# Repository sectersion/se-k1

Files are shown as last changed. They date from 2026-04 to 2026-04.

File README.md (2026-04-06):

# Secure Element K1

This project is a small hardware password vault and crypto cold wallet using an ESP32-S3, a TPM (SLB9670), and a W25Q-series SPI flash chip.  

I created this project because a family member was talking about crypto wallets, and it gave me the idea of password managers. Online password managers are tied to one login and if that gets breached, all your accounts are gone. This implements a secure way to hold passwords, fully offline, not relying on cloud providers like Google.

## Features

- ESP32-S3 with USB HID keyboard output  
- TPM-backed master key for decrypting stored passwords  
- External SPI flash for record storage (ID, encrypted password, hashed PIN, MAC)  
- Button-based keypad input  
- PIN verification using SHA-256 with device-unique salt  
- Short-lived in-memory plaintext handling

## System

1. User enters a 4-digit record ID.  
2. Device loads the corresponding record from flash.  
3. User enters a 6-digit PIN.  
4. PIN is hashed and compared to the stored hash.  
5. If valid, the TPM unseals the master key.  
6. The encrypted password is decrypted using the TPM-provided key.  
7. The password is typed over USB HID.  
8. Plaintext is cleared.

## Components

| Designator | Footprint | Quantity | Value | LCSC Part # |
|---|---|---|---|---|
| 3V3 | TestPoint_Pad_D1.0mm | 1 | 3V3 | |
| 5V | TestPoint_Pad_D1.0mm | 1 | 5V | |
| BT1 | BatteryHolder_Renata_SMTU2032-LF_1x2032 | 1 | SMTU2032-LF | C18212226 |
| C1, C3, C7 | 0402 | 3 | 10uF | C315248 |
| C2 | CP_Elec_6.3x5.8 | 1 | 10uF | C128459 |
| C4 | 0402 | 1 | 0.1uF | C60474 |
| C5, C6 | 0402 | 2 | 100nF | C60474 |
| C8 | 0805 | 1 | 100nF | C49678 |
| D1 | D_SMA | 1 | SS14 | C2837270 |
| J1 | USB_C_Receptacle_HRO_TYPE-C-31-M-12 | 1 | USB_C_Receptacle_USB2.0_14P | C2765186 |
| R1, R2 | 0402 | 2 | 5.1k | C105872 |
| R3, R4, R5, R6, R8 | 0402 | 5 | 10k | C60490 |
| RST | SW_TS-1088-AR02016 | 1 | TS-1088-AR02016 | C720477 |
| RXD | TestPoint_Pad_D1.0mm | 1 | RX | |
| S1 | SW_TS-1088-AR02016 | 1 | 1 | C720477 |
| S2 | SW_TS-1088-AR02016 | 1 | 4 | C720477 |
| S3 | SW_TS-1088-AR02016 | 1 | 7 | C720477 |
| S4 | SW_TS-1088-AR02016 | 1 | 2 | C720477 |
| S5 | SW_TS-1088-AR02016 | 1 | 5 | C720477 |
| S6 | SW_TS-1088-AR02016 | 1 | 8 | C720477 |
| S7 | SW_TS-1088-AR02016 | 1 | 3 | C720477 |
| S8 | SW_TS-1088-AR02016 | 1 | 6 | C720477 |
| S9 | SW_TS-1088-AR02016 | 1 | 9 | C720477 |
| S10 | SW_TS-1088-AR02016 | 1 | 0 | C720477 |
| TXD | TestPoint_Pad_D1.0mm | 1 | TX | |
| U1 | ESP32-S2-MINI-1U | 1 | ESP32-S3-MINI-1U | C2980299 |
| U2 | QFN50P500X500X90-33N | 1 | SLM9670AQ20FW1311XTMA1 | C2651754 |
| U3 | SOIC127P790X216-8N | 1 | W25Q16JVSSIQ | C82317 |
| U4 | SOT-223-3_TabPin2 | 1 | AMS1117-3.3 | C6186 |

## Record Format

Each stored record contains:

- id: 4 bytes  
- encrypted_password: fixed length  
- encrypted_pin: 16-byte truncated SHA-256 hash  
- mac: record integrity field

## Pictures
3D model:


PCB:


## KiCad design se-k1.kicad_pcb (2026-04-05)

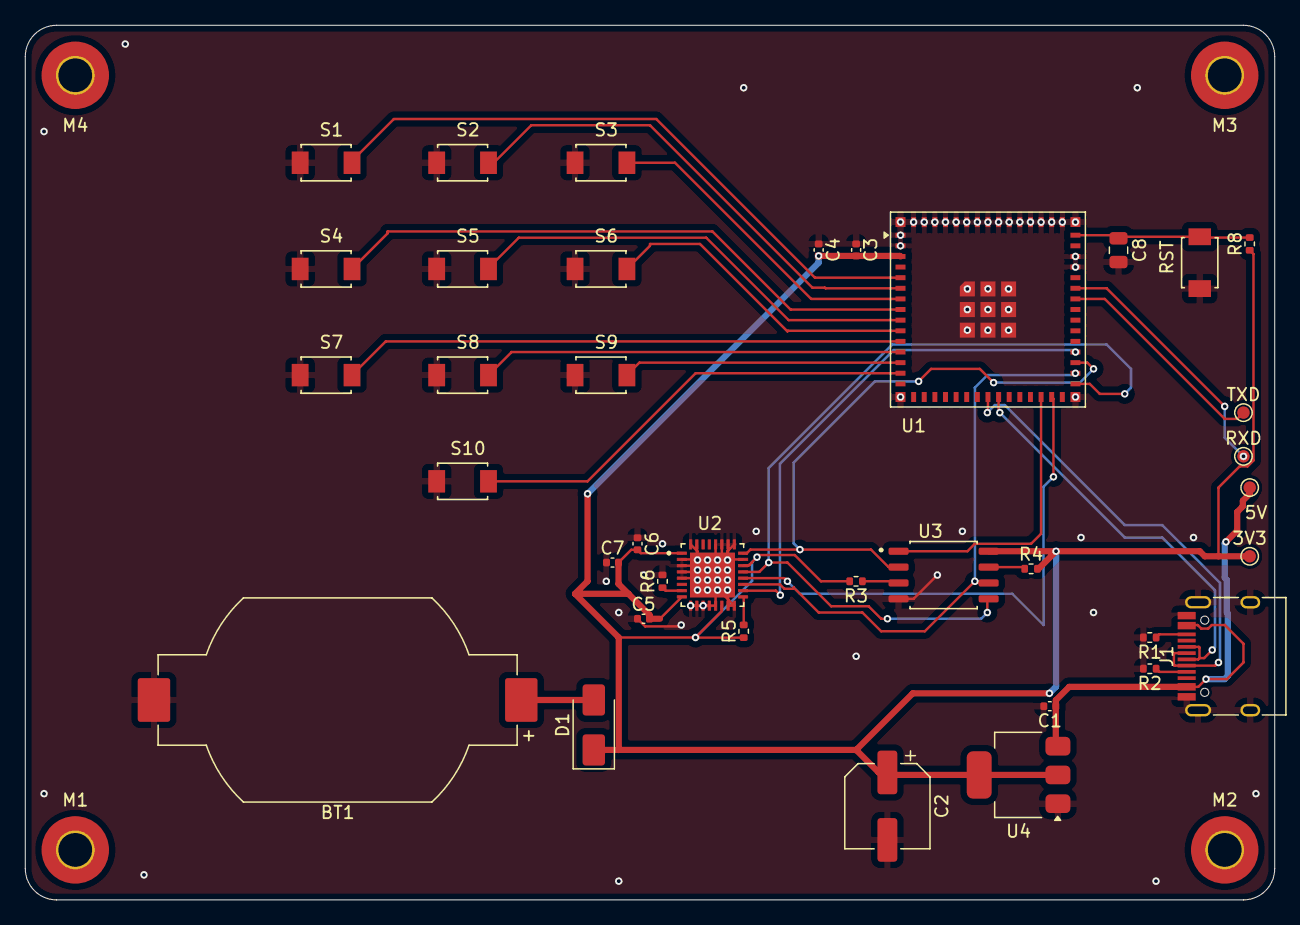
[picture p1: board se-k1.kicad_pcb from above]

Board: 2 copper layers, 100.0 x 70.0 mm, 41 parts (0 on the bottom side), 31 nets.

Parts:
3V3: 3V3; TestPoint_Pad_D1.0mm
5V: 5V; TestPoint_Pad_D1.0mm
BT1: SMTU2032-LF; BatteryHolder_Renata_SMTU2032-LF_1x2032
C1, C3, C7: 10uF; C_0402_1005Metric
C2: 10uF; CP_Elec_6.3x5.8
C4: 0.1uF; C_0402_1005Metric
C5, C6: 100nF; C_0402_1005Metric
C8: 100nF; C_0805_2012Metric
D1: SS14; D_SMA
J1: USB_C_Receptacle_USB2.0_14P; USB_C_Receptacle_HRO_TYPE-C-31-M-12
M1, M2, M3, M4: MountingHole_2.7mm_M2.5_Pad_TopOnly
R1, R2: 5.1k; R_0402_1005Metric
R3, R4, R5, R6, R8: 10k; R_0402_1005Metric
RST: TS-1088-AR02016; SW_TS-1088-AR02016
RXD: RX; TestPoint_Pad_D1.0mm
S1: 1; SW_TS-1088-AR02016
S2: 4; SW_TS-1088-AR02016
S3: 7; SW_TS-1088-AR02016
S4: 2; SW_TS-1088-AR02016
S5: 5; SW_TS-1088-AR02016
S6: 8; SW_TS-1088-AR02016
S7: 3; SW_TS-1088-AR02016
S8: 6; SW_TS-1088-AR02016
S9: 9; SW_TS-1088-AR02016
S10: 0; SW_TS-1088-AR02016
TXD: TX; TestPoint_Pad_D1.0mm
U1: ESP32-S3-MINI-1U; ESP32-S2-MINI-1U
U2: SLM9670AQ20FW1311XTMA1; QFN50P500X500X90-33N
U3: W25Q16JVSSIQ; SOIC127P790X216-8N
U4: AMS1117-3.3; SOT-223-3_TabPin2

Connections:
+3V3: 3V3.1, C2.1, C3.2, C4.2, C5.2, C6.2, C7.2, D1.1 (K), R3.2, R4.2, R5.1, R8.1, U1.3 (3V3), U2.1 (NCI/VDD), U2.8 (VDD), U2.14 (NCI/VDD), U2.22 (VDD), U3.8 (VCC), U4.2 (VO)
+5V: 5V.1, C1.1, J1.A4 (VBUS), J1.A9 (VBUS), J1.B4 (VBUS), J1.B9 (VBUS), U4.3 (VI)
/B0: S10.2, U1.14 (IO10)
/B1: S1.2, U1.5 (IO1)
/B2: S2.2, U1.6 (IO2)
/B3: S3.2, U1.7 (IO3)
/B4: S4.B4, U1.8 (IO4)
/B5: S5.2, U1.9 (IO5)
/B6: S6.2, U1.10 (IO6)
/B7: S7.2, U1.11 (IO7)
/B8: S8.2, U1.12 (IO8)
/B9: S9.2, U1.13 (IO9)
/D+: J1.A6 (D+), J1.B6 (D+), U1.24 (USB_D+)
/D-: J1.A7 (D-), J1.B7 (D-), U1.23 (USB_D-)
/FLASH_CS: U1.28 (IO33), U3.1 (~CS)
/MISO: U1.33 (IO37), U2.24 (MISO), U3.2 (DO(IO1))
/MOSI: U1.31 (IO35), U2.21 (MOSI), U3.5 (DI(IO0))
/SCLK: U1.32 (IO36), U2.19 (SCLK), U3.6 (CLK)
/TPM_CS: U1.29 (IO34), U2.20 (~CS)
/TPM_PIRQ: U1.34 (IO38), U2.18 (~PIRQ)
GND: BT1.2, C1.2, C2.2, C3.1, C4.1, C5.1, C6.1, C7.1, C8.2, J1.A1 (GND), J1.A12 (GND), J1.B1 (GND), J1.B12 (GND), J1.S1 (SHIELD), R1.2, R2.2, R6.2, RST.1, S1.1, S2.1, S3.1, S4.1, S5.1, S6.1, S7.1, S8.1, S9.1, S10.1, U1.1 (GND), U1.2 (GND), U1.42 (GND), U1.43 (GND), U1.46 (GND), U1.47 (GND), U1.48 (GND), U1.49 (GND), U1.50 (GND), U1.51 (GND), U1.52 (GND), U1.53 (GND), U1.54 (GND), U1.55 (GND), U1.56 (GND), U1.57 (GND), U1.58 (GND), U1.59 (GND), U1.60 (GND), U1.61 (GND), U1.62 (GND), U1.63 (GND), U1.64 (GND), U1.65 (GND), U2.2 (GND), U2.3 (NCI), U2.4 (NCI), U2.5 (NCI), U2.9 (GND), U2.10 (NCI), U2.11 (NCI), U2.12 (NCI), U2.13 (NCI), U2.15 (NCI), U2.16 (NCI/GND), U2.23 (GND), U2.25 (NCI), U2.26 (NCI), U2.27 (NCI), U2.28 (NCI), U2.31 (NCI), U2.32 (GND), U2.33 (EXP), U3.4 (GND), U4.1 (GND)
unnamed: BT1.1, D1.2 (A)
unnamed: J1.A5 (CC1), R2.1
unnamed: J1.B5 (CC2), R1.1
unnamed: C8.1, R8.2, RST.2, U1.45 (EN)
unnamed: RXD.1, U1.40 (RXD0)
unnamed: TXD.1, U1.39 (TXD0)
unnamed: R6.1, U2.7 (PP)
unnamed: R5.2, U2.17 (~RST)
unnamed: R4.1, U3.7 (~HOLD/RESET(IO3))
unnamed: R3.1, U3.3 (~WP(IO2))

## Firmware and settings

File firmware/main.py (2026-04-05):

from machine import Pin, SPI
import time
import machine
import button_manager
import flash
import pinlayout
from tpm import SLB9670
import uhashlib
from hid import type_string


def init_flash():
    global flash0
    flash0 = flash.FlashStorage(spi=pinlayout.spi, cs_pin=pinlayout.flash_cs)
    return flash0


def init_tpm():
    global tpm
    tpm = SLB9670(spi_bus=pinlayout.spi, cs_pin=pinlayout.tpm_cs, irq_pin=pinlayout.tpm_irq)
    return tpm


def hash_pin(pin_str: str) -> bytes:
    # SHA256(unique_id, pin)
    h = uhashlib.sha256()
    h.update(machine.unique_id())
    h.update(pin_str.encode())
    return h.digest()[:16]


def read_id():
    return button_manager.read_pad(4)


def read_pin():
    return button_manager.read_pad(6)



def flash_read_record(record_id):
    addr = flash0.find_record_by_id(record_id)
    return flash0.read_record(addr)


def tpm_authorize(record, pin_input, master_key_handle):
    # check pin
    if hash_pin(pin_input) != record["encrypted_pin"]:
        return None

    # tpm decrypt
    tpm.start_hmac_session()
    key_handle = tpm.load_master_key(master_key_handle)
    return tpm.decrypt_with_master(record["encrypted_password"], key_handle)


def output_secret(secret):
    if secret is None:
        print("debug.InvalidPIN")
    else:
        type_string(secret)

def handle_user_session():
    uid = read_id()
    rec = flash_read_record(uid)
    pin = read_pin()

    MASTER_KEY = 0x81000001
    secret = tpm_authorize(rec, pin, MASTER_KEY)
    output_secret(secret)





def main_loop():
    while True:
        handle_user_session()


def main():
    init_flash()
    init_tpm()
    main_loop()


if __name__ == "__main__":
    main()

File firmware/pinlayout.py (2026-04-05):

from machine import Pin

#spi
SPI_BUS = 1
SPI_SCK = 36
SPI_MISO = 37
SPI_MOSI = 35

#individial cs
FLASH_CS = 33
TPM_CS = 34

#buttons
BUTTON_1 = 1
BUTTON_2 = 2
BUTTON_3 = 3
BUTTON_4 = 4
BUTTON_5 = 5
BUTTON_6 = 6
BUTTON_7 = 7
BUTTON_8 = 8
BUTTON_9 = 9
BUTTON_0 = 10

#tpm
TPM_IRQ = 38

from machine import Pin, SPI

# SPI pins
spi = SPI(
    SPI_BUS,
    baudrate=4_000_000,
    sck=Pin(SPI_SCK),
    mosi=Pin(SPI_MOSI),
    miso=Pin(SPI_MISO),
)

# Chip-select pins
flash_cs = Pin(FLASH_CS, Pin.OUT, value=1)
tpm_cs = Pin(TPM_CS, Pin.OUT, value=1)

# Buttons
button_1 = Pin(BUTTON_1, Pin.IN, Pin.PULL_UP)
button_2 = Pin(BUTTON_2, Pin.IN, Pin.PULL_UP)
button_3 = Pin(BUTTON_3, Pin.IN, Pin.PULL_UP)
button_4 = Pin(BUTTON_4, Pin.IN, Pin.PULL_UP)
button_5 = Pin(BUTTON_5, Pin.IN, Pin.PULL_UP)
button_6 = Pin(BUTTON_6, Pin.IN, Pin.PULL_UP)
button_7 = Pin(BUTTON_7, Pin.IN, Pin.PULL_UP)
button_8 = Pin(BUTTON_8, Pin.IN, Pin.PULL_UP)
button_9 = Pin(BUTTON_9, Pin.IN, Pin.PULL_UP)
button_0 = Pin(BUTTON_0, Pin.IN, Pin.PULL_UP)

# TPM IRQ pin
tpm_irq = Pin(TPM_IRQ, Pin.IN)
